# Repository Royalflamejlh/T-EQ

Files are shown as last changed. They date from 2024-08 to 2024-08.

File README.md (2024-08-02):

# T EQ Pedal

This project's goal is to just make a simple home made equalizer pedal for a standard guitar.

The project started work from schematic of the [Rock Bottom EQ](https://www.diyguitarpedals.com.au/shop/boms/Rock%20Bottom%20EQ.pdf) and adapted it into our own schematic.

## Current Status

As of right now the first prototype of the pedal has been tested and we found some pretty big grounding problems, along with instability in the power supply circuity.

## Editing

The project can be opened and edited in KiCad 8

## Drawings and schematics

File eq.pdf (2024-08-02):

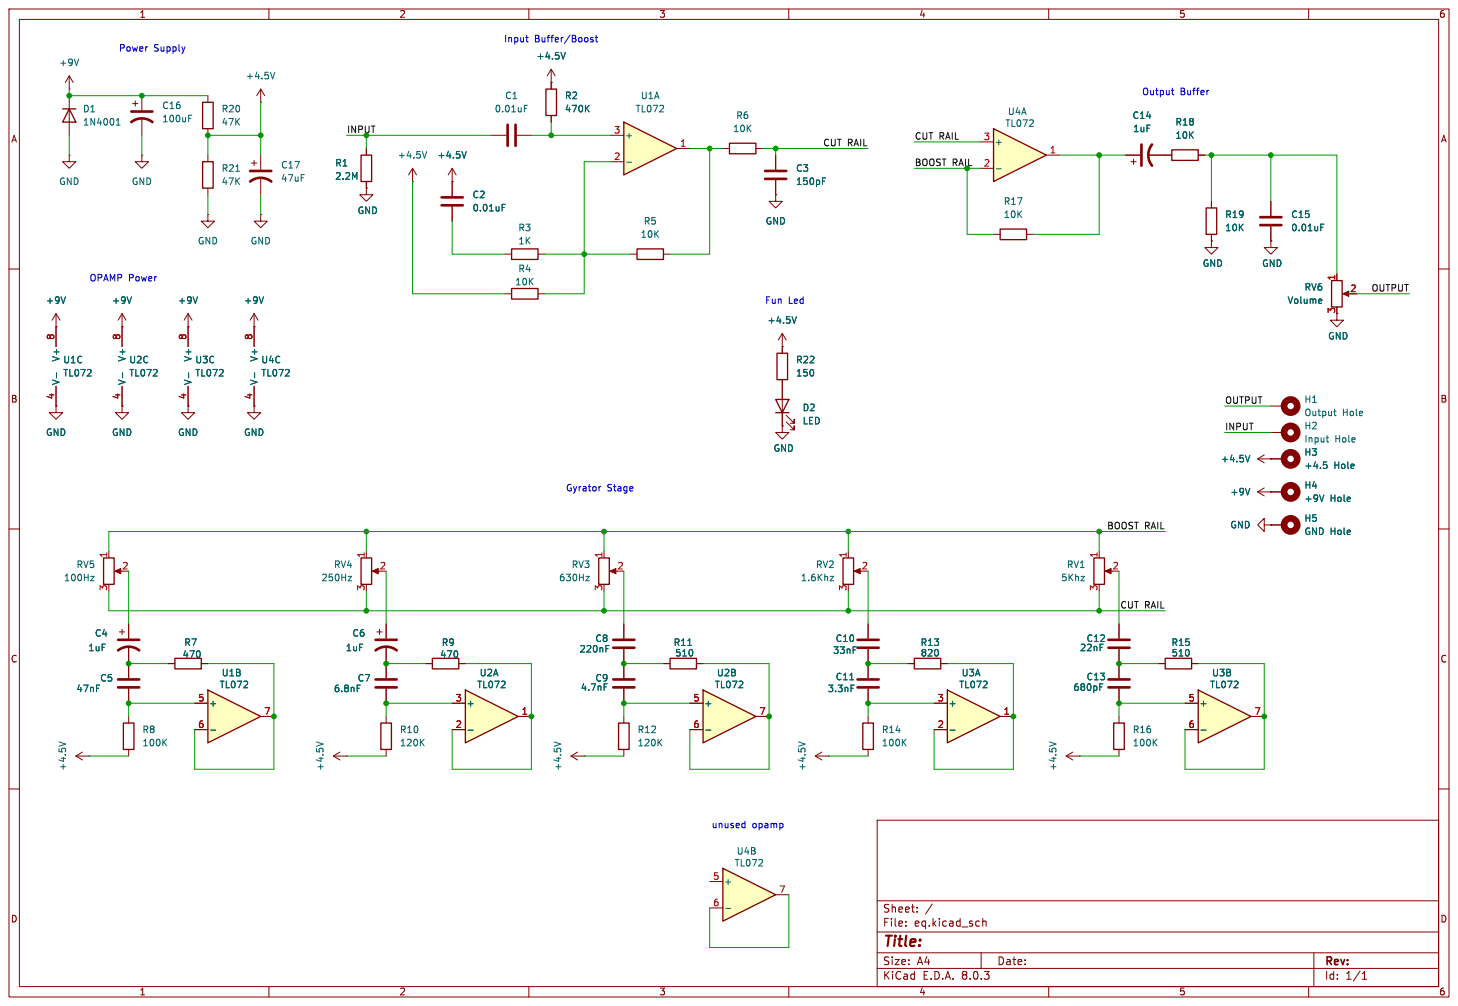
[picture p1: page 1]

Output Buffer Gyrator Stage R1

Id: 1/1 Title: File: eq.kicad_sch Sheet: / V- 4 V+

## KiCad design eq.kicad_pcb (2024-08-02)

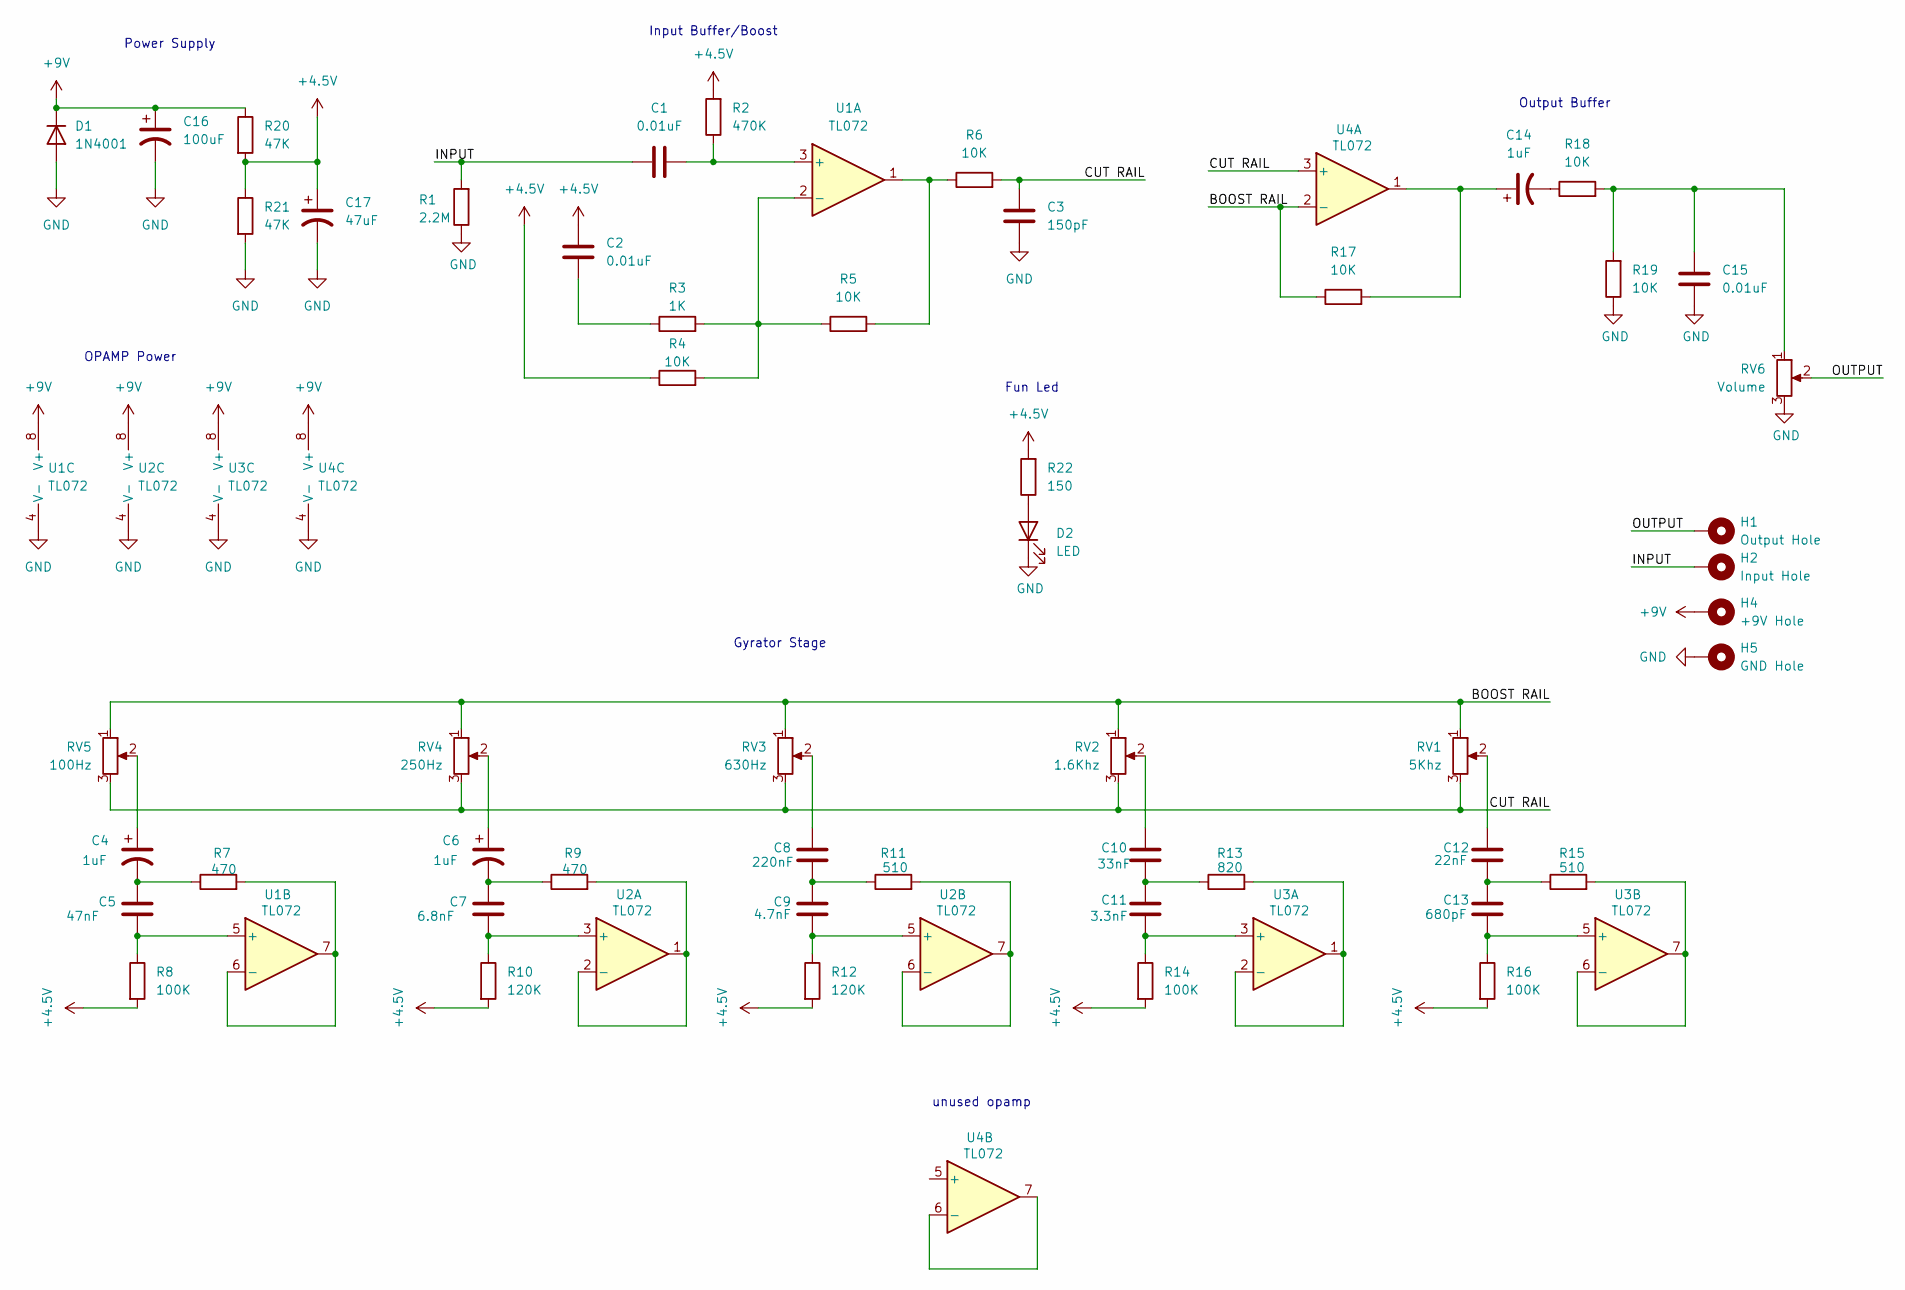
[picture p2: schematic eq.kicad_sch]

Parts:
C1, C2: 0.01uF; C_Rect_L7.2mm_W3.5mm_P5.00mm_FKS2_FKP2_MKS2_MKP2
C3: 150pF; C_Rect_L7.2mm_W5.5mm_P5.00mm_FKS2_FKP2_MKS2_MKP2
C4, C6, C14: 1uF; C_Radial_D4.0mm_H7.0mm_P1.50mm
C5: 47nF; C_Rect_L13.0mm_W6.0mm_P10.00mm_FKS3_FKP3_MKS4
C7: 6.8nF; C_Rect_L18.0mm_W8.0mm_P15.00mm_FKS3_FKP3
C8: 220nF; C_Rect_L9.0mm_W3.2mm_P7.50mm_MKT
C9: 4.7nF; C_Rect_L7.0mm_W2.5mm_P5.00mm
C10: 33nF; C_Rect_L18.0mm_W9.0mm_P15.00mm_FKS3_FKP3
C11: 3.3nF; C_Rect_L11.0mm_W6.4mm_P10.00mm_MKT
C12: 22nF; C_Rect_L13.0mm_W5.0mm_P10.00mm_FKS3_FKP3_MKS4
C13: 680pF; C_Disc_D16.0mm_W5.0mm_P10.00mm
C15: 0.01uF; C_Rect_L13.0mm_W5.0mm_P10.00mm_FKS3_FKP3_MKS4
C16: 100uF; CP_Radial_D8.0mm_P3.50mm
C17: 47uF; CP_Radial_D5.0mm_P2.00mm
D1: 1N4001; D_5W_P5.08mm_Vertical_AnodeUp
D2: LED; LED_D4.0mm
H1: Output Hole; MountingHole_5.5mm_Pad
H2: Input Hole; MountingHole_5.5mm_Pad
H4: +9V Hole; MountingHole_5.5mm_Pad
H5: GND Hole; MountingHole_5.5mm_Pad
R1: 2.2M; R_Axial_DIN0207_L6.3mm_D2.5mm_P7.62mm_Horizontal
R2: 470K; R_Axial_DIN0207_L6.3mm_D2.5mm_P7.62mm_Horizontal
R3: 1K; R_Axial_DIN0309_L9.0mm_D3.2mm_P12.70mm_Horizontal
R4, R5, R6, R17, R18, R19: 10K; R_Axial_DIN0207_L6.3mm_D2.5mm_P7.62mm_Horizontal
R7, R9: 470; R_Axial_DIN0207_L6.3mm_D2.5mm_P7.62mm_Horizontal
R8, R14, R16: 100K; R_Axial_DIN0207_L6.3mm_D2.5mm_P7.62mm_Horizontal
R10, R12: 120K; R_Axial_DIN0207_L6.3mm_D2.5mm_P7.62mm_Horizontal
R11, R15: 510; R_Axial_DIN0207_L6.3mm_D2.5mm_P7.62mm_Horizontal
R13: 820; R_Axial_DIN0207_L6.3mm_D2.5mm_P7.62mm_Horizontal
R20, R21: 47K; R_Axial_DIN0207_L6.3mm_D2.5mm_P7.62mm_Horizontal
R22: 150; R_Axial_DIN0207_L6.3mm_D2.5mm_P7.62mm_Horizontal
RV1: 5Khz; Potentiometer_Omeg_PC16BU_Vertical
RV2: 1.6Khz; Potentiometer_Omeg_PC16BU_Vertical
RV3: 630Hz; Potentiometer_Omeg_PC16BU_Vertical
RV4: 250Hz; Potentiometer_Omeg_PC16BU_Vertical
RV5: 100Hz; Potentiometer_Omeg_PC16BU_Vertical
RV6: Volume; Potentiometer_Omeg_PC16BU_Vertical
U1, U2, U3, U4: TL072; DIP794W45P254L959H508Q8

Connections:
+4.5V: C2.1, C17.1, R2.2, R4.1, R8.2, R10.2, R12.2, R14.2, R16.2, R20.2, R21.1, R22.2
+9V: C16.1, D1.1 (K), H4.1, R20.1, U1.8 (V+), U2.8 (V+), U3.8 (V+), U4.8 (V+)
/BOOST RAIL: R17.1, RV1.1, RV2.1, RV3.1, RV4.1, RV5.1, U4.2 (-); also elsewhere on the board
/CUT RAIL: C3.1, R6.2, RV1.3, RV2.3, RV3.3, RV4.3, RV5.3, U4.3 (+); also elsewhere on the board
/INPUT: C1.1, H2.1, R1.2
/OUTPUT: H1.1, RV6.2
GND: C3.2, C15.2, C16.2, C17.2, D1.2 (A), D2.1 (K), H5.1, R1.1, R19.1, R21.2, RV6.3, U1.4 (V-), U2.4 (V-), U3.4 (V-), U4.4 (V-)
unnamed: C2.2, R3.1
unnamed 8: C4.1, RV5.2; also elsewhere on the board
unnamed: C4.2, C5.1, R7.1
unnamed 10: C6.1, RV4.2; also elsewhere on the board
unnamed: C6.2, C7.1, R9.1
unnamed 12: C8.1, RV3.2; also elsewhere on the board
unnamed: C8.2, C9.1, R11.1
unnamed 14: C10.1, RV2.2; also elsewhere on the board
unnamed: C10.2, C11.1, R13.1
unnamed 16: C12.1, RV1.2; also elsewhere on the board
unnamed: C12.2, C13.1, R15.1
unnamed: C14.1, R17.2, U4.1
unnamed: C14.2, R18.1
unnamed: C15.1, R18.2, R19.2, RV6.1
unnamed: D2.2 (A), R22.1
unnamed: R5.2, R6.1, U1.1
unnamed: C1.2, R2.1, U1.3 (+)
unnamed: R3.2, R4.2, R5.1, U1.2 (-)
unnamed: C5.2, R8.1, U1.5 (+)
unnamed: R7.2, U1.6 (-), U1.7
unnamed: C7.2, R10.1, U2.3 (+)
unnamed: R9.2, U2.1, U2.2 (-)
unnamed: C9.2, R12.1, U2.5 (+)
unnamed: R11.2, U2.6 (-), U2.7
unnamed: C11.2, R14.1, U3.3 (+)
unnamed: R13.2, U3.1, U3.2 (-)
unnamed: C13.2, R16.1, U3.5 (+)
unnamed: R15.2, U3.6 (-), U3.7
unnamed: U4.6 (-), U4.7

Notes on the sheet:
Input Buffer/Boost
Gyrator Stage
Power Supply
Output Buffer
OPAMP Power
unused opamp
Fun Led

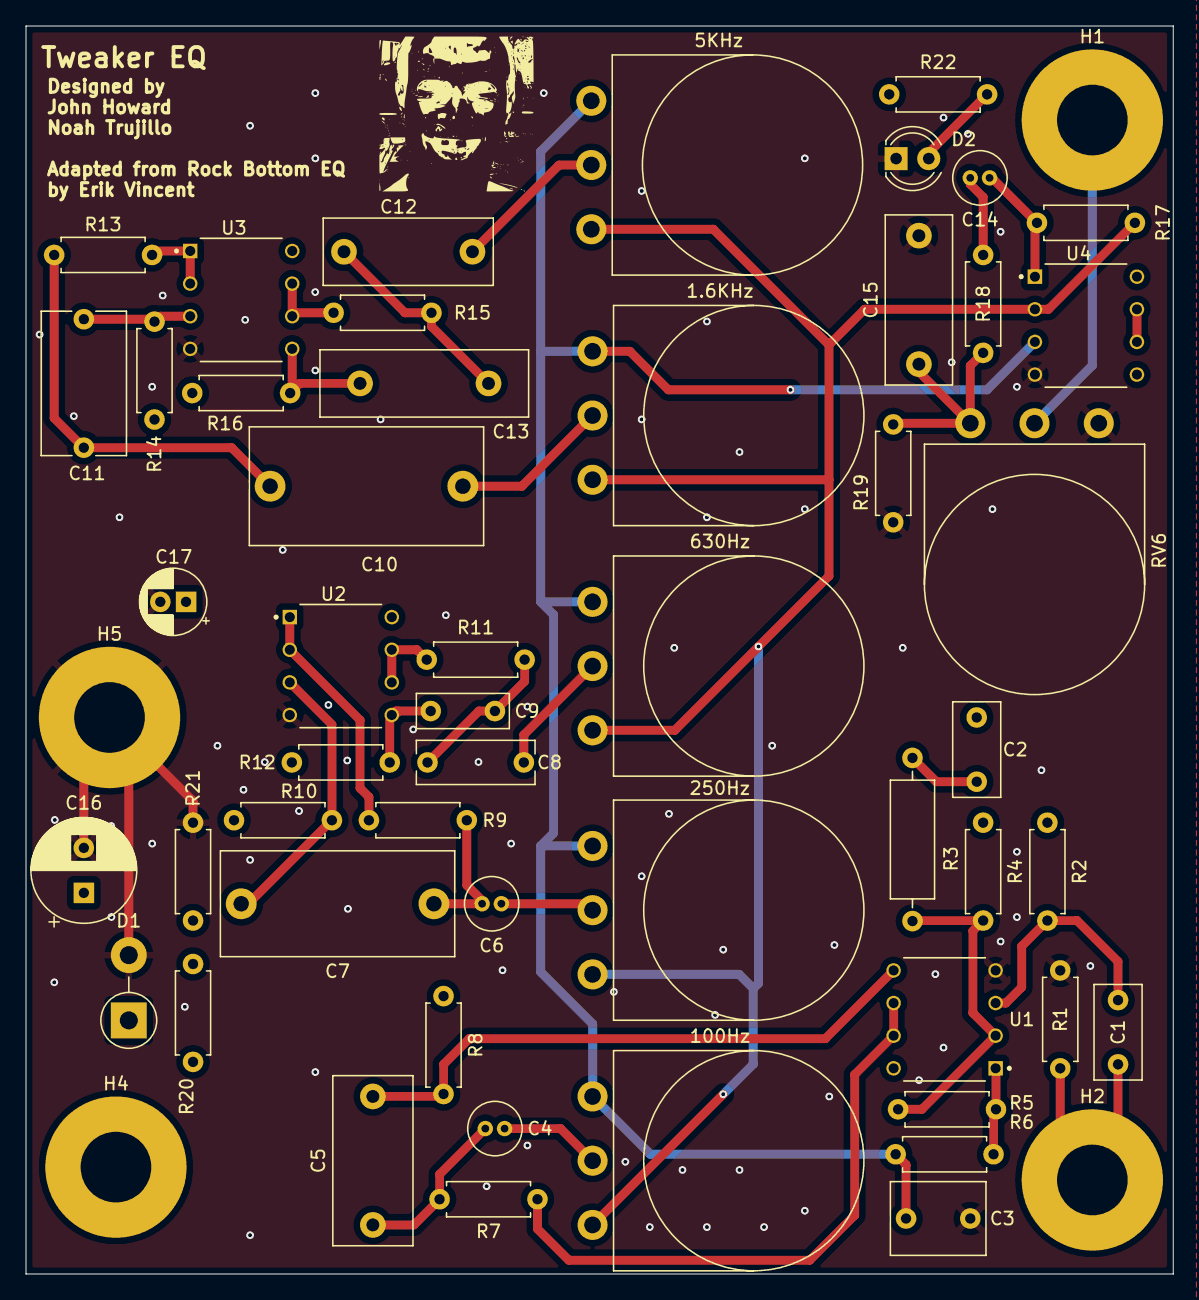
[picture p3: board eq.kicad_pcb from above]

Board: 4 copper layers, 89.3 x 97.1 mm, 55 parts (0 on the bottom side), 36 nets.

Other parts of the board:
1.6KHz: 1.6Khz; Potentiometer_Omeg_PC16BU_Vertical
5KHz: 5Khz; Potentiometer_Omeg_PC16BU_Vertical
100Hz: 100Hz; Potentiometer_Omeg_PC16BU_Vertical
250Hz: 250Hz; Potentiometer_Omeg_PC16BU_Vertical
630Hz: 630Hz; Potentiometer_Omeg_PC16BU_Vertical

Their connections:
/BOOST RAIL: 1.6KHz.1, 5KHz.1, 100Hz.1, 250Hz.1, 630Hz.1; also elsewhere on the board
/CUT RAIL: 1.6KHz.3, 5KHz.3, 100Hz.3, 250Hz.3, 630Hz.3; also elsewhere on the board
unnamed 8: 100Hz.2; also elsewhere on the board
unnamed 10: 250Hz.2; also elsewhere on the board
unnamed 12: 630Hz.2; also elsewhere on the board
unnamed 14: 1.6KHz.2; also elsewhere on the board
unnamed 16: 5KHz.2; also elsewhere on the board
